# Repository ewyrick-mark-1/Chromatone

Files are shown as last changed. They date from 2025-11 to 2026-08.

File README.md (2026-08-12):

# Chromatone

**Author:** Elliot Wyrick

## Overview

Chromatone is an embedded audio visualizer running on the Raspberry Pi RP2350. It samples audio through the ADC, performs a real-time FFT, detects musical notes, and drives an RGB LED output based on the results.

## [Demo video:](https://youtu.be/pOVmz1aZbJg)

Watch the demo (https://youtu.be/pOVmz1aZbJg)

## Hardware

- **MCU:** Raspberry Pi RP2350 (overclocked to 300 MHz)
- **Input:** Analog microphone on ADC channel 0 (GPIO 40)
- **Output:** RGB LED via PWM on GPIO 37–39
- **Schematics/PCB:** KiCad project files located in `KiCad/`

## How It Works

Audio is captured at 20 kHz using DMA ping-pong buffers. Each buffer triggers a 16384 point FFT with 50% overlap and a Hanning window applied. Detected frequency peaks are mapped to MIDI notes (A0–C8), and the corresponding hue is output to the RGB LED.

Two display modes are available (toggled via `display_mode` in `main.c`):
- **Mode 0:** Logarithmic frequency spectrum
- **Mode 1:** Musical note detection

## Color Math

Each of the 12 chromatic notes is assigned a fixed hue evenly spaced around the color wheel (360° / 12 = 30° per note), with C at 0° (red) through B at 330° (pink).

Detected peaks are converted to a note index using the standard MIDI formula:

```
n = 12 × log₂(f / 440) + 69
```

When multiple notes are detected simultaneously, their hues are blended using a **circular weighted average**- each hue is converted to a unit vector on the color wheel, weighted by FFT magnitude, and the vectors are summed:

```
x = Σ( cos(hue_i) × weight_i )
y = Σ( sin(hue_i) × weight_i )
blended_hue = atan2(y, x)
```

This handles wraparound correctly (e.g. blending 10° and 350° yields 0°, not 180°).

The blended hue is then smoothed over time using an exponential moving average on the shortest angular path (15% per frame) to avoid jarring color jumps between notes.

Finally, the smoothed hue is converted from HSV (full saturation and brightness) to RGB via the standard piecewise HSV→RGB formula and output as an 8-bit PWM duty cycle on each channel.

## Build & Flash

This project uses [PlatformIO](https://platformio.org/) with the Proton board target.

```
pio run
pio run --target upload
```

Serial monitor at 115200 baud:
```
pio device monitor
```

Alternativly, and what I used during development, the platform IO extension works well. It provides gui upload and monitor buttons.

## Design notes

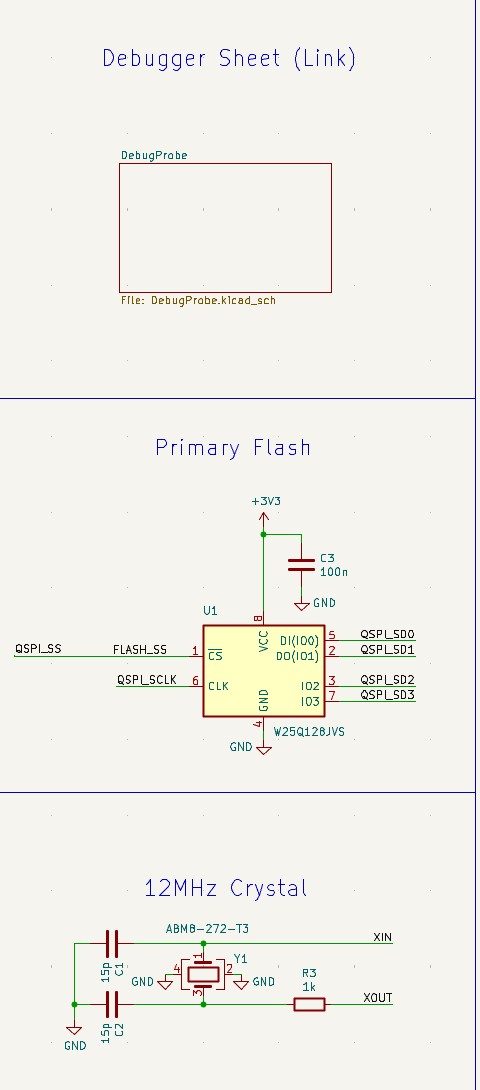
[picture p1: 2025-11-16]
KiCad/4% possibilities/Proton Schematics/Flash & XOSC schem.jpg

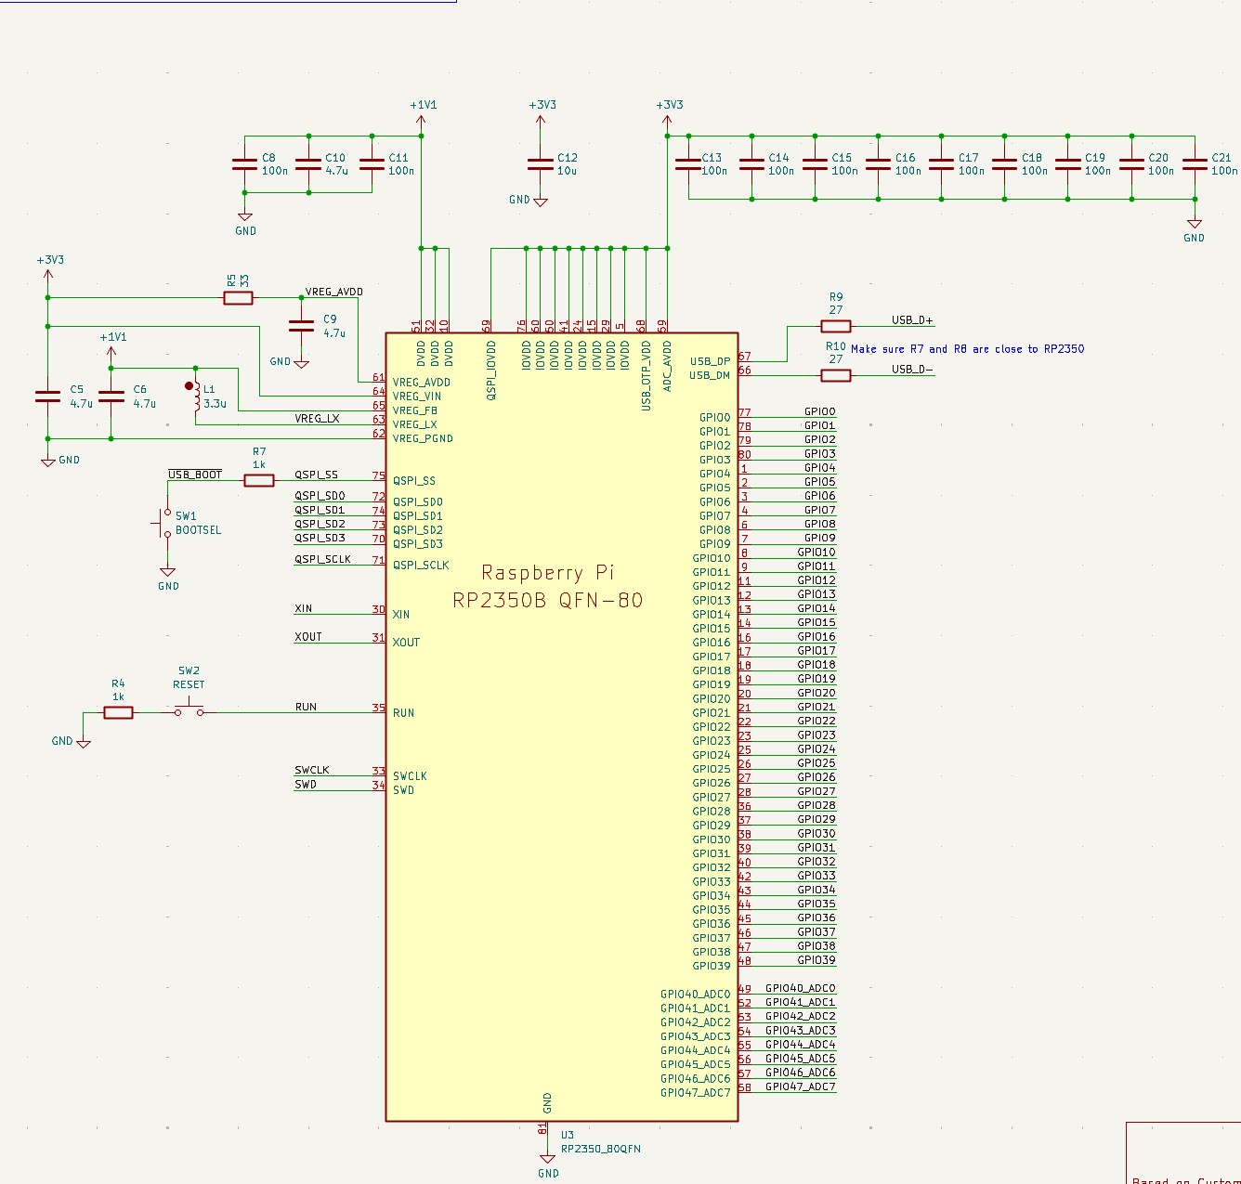
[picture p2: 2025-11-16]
KiCad/4% possibilities/Proton Schematics/Proton main schem.jpg

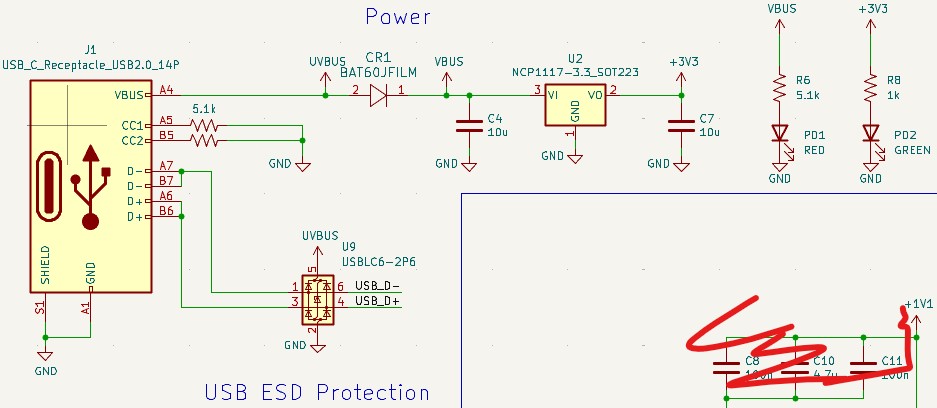
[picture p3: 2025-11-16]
KiCad/4% possibilities/Proton Schematics/Power schem.jpg

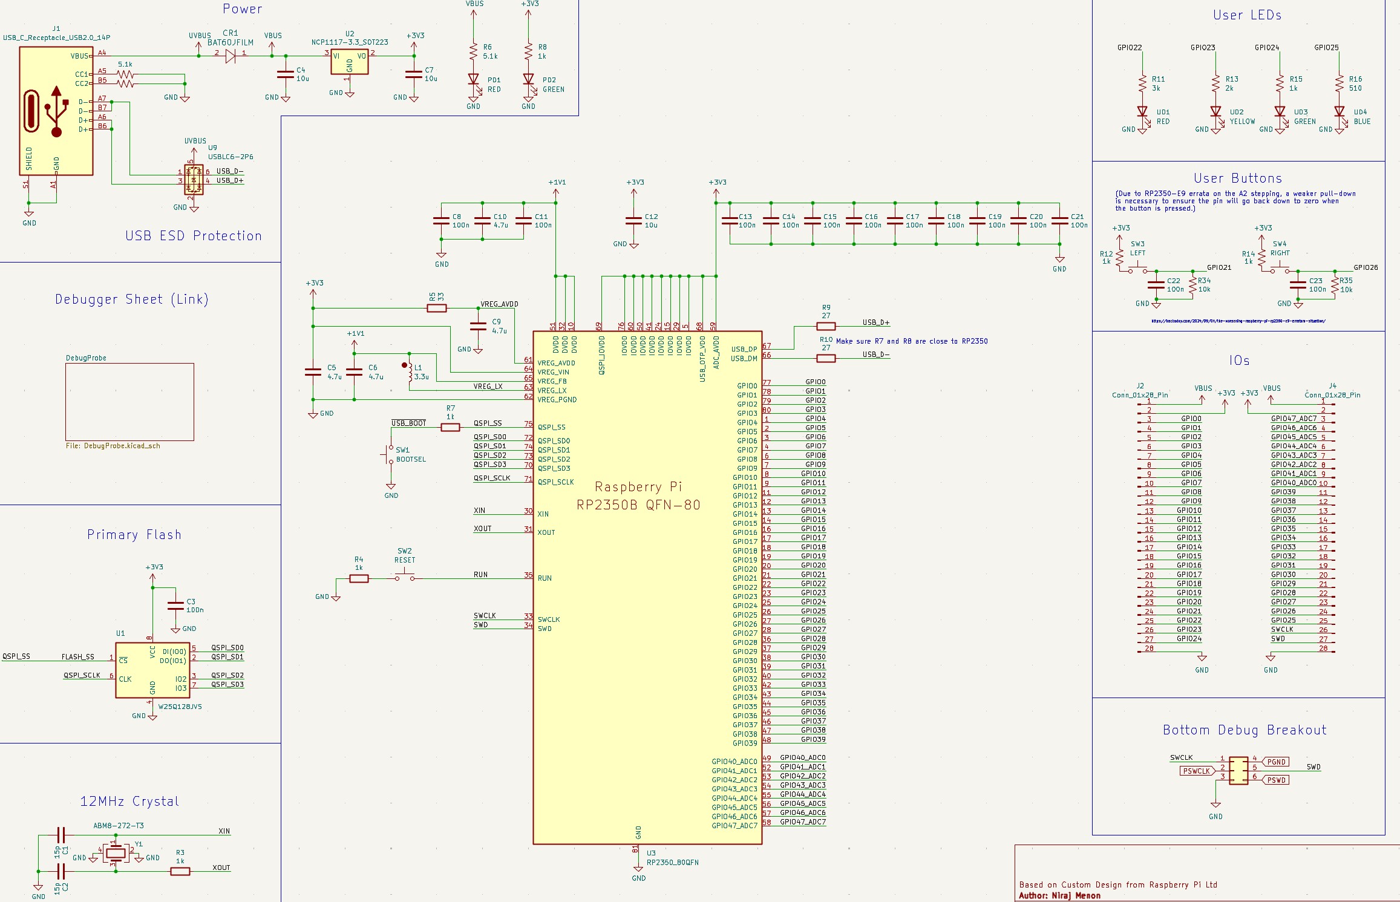
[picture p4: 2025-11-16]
KiCad/4% possibilities/Proton Schematics/Proton Schematic.jpg

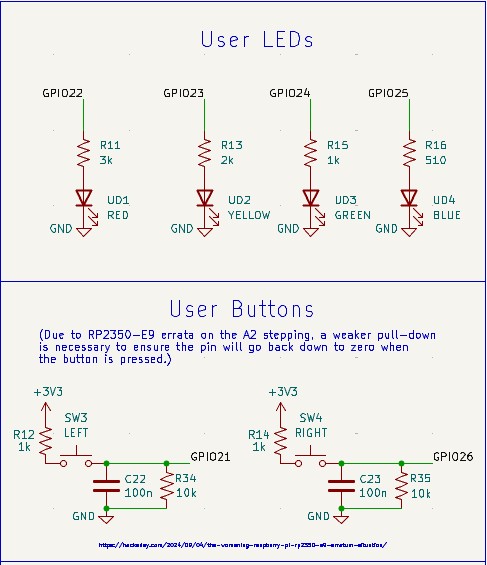
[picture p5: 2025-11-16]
KiCad/4% possibilities/Proton Schematics/optional Buttons schem.jpg

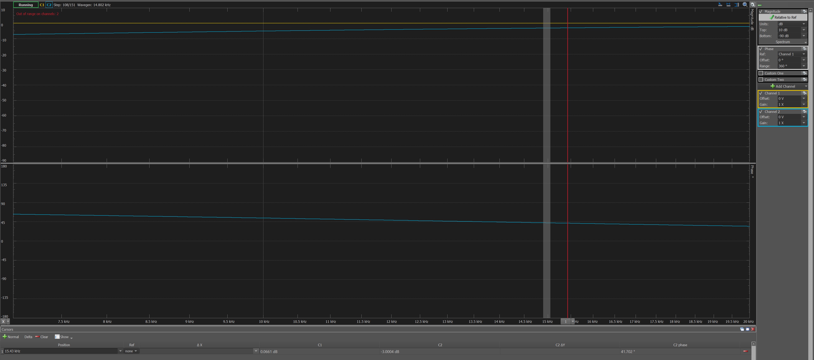
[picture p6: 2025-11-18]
HPF.jpg

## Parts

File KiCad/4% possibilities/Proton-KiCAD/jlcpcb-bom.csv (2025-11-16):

Designator | Footprint | Quantity | Value | LCSC Part #
C1, C2, C24, C25 | 402 | 4 | 15p | C1548
C10, C5, C6, C9 | 402 | 4 | 4.7u | C23733
C11, C13, C14, C15, C16, C17, C18, C19, C20, C21, C22, C23, C28, C29, C3, C30, C33, C35, C36, C37, C38, C39, C40, C41, C42, C8 | 402 | 26 | 100n | C1525
C12, C26, C4, C7 | 805 | 4 | 10u | C15850
C27, C32 | 603 | 2 | 10u | C19702
C31, C34 | 402 | 2 | 1u | C52923
CR1, CR2 | CR_60JFILM_STM | 2 | BAT60JFILM | C133103
D1 | 402 | 1 | RED | C397045
D2, D4 | 402 | 2 | GREEN | C434446
D3, D5 | 402 | 2 | YELLOW | C130721
J1, J5 | USB_C_Receptacle_G-Switch_GT-USB-7010ASV | 2 | USB_C_Receptacle_USB2.0_14P | C2988369
L1 | L_pol_2016 | 1 | 3.3u | C42411119
PD1, UD1 | 805 | 2 | RED | C2295
PD2, UD3 | 805 | 2 | GREEN | C2297
R1, R18, R19, R2, R6, R8 | 402 | 4 | 5.1k | C25905
R10, R21, R22, R9 | 402 | 4 | 27 | C137890
R11 | 402 | 1 | 3k | C25559
R13 | 402 | 1 | 2k | C4109
R16 | 402 | 1 | 510 | C25123
R12, R14, R15, R17, R20, R3, R4, R7 | 402 | 13 | 1k | C11702
R34, R35 | 402 | 2 | 10k | C25531
R23, R31, R33 | 402 | 5 | 470 | C25117
R30, R32 | 402 | 2 | 2k | C4109
R24, R25, R26, R27, R28, R29 | 402 | 6 | 100 | C25076
R5 | 402 | 1 | 33 | C25105
SW1 | SW_SPST_PTS647_Sx38 | 1 | BOOTSEL | C2689502
SW2 | SW_SPST_PTS647_Sx38 | 1 | RESET | C2689502
SW3 | SW_SPST_PTS647_Sx38 | 1 | LEFT | C2689502
SW4 | SW_SPST_PTS647_Sx38 | 1 | RIGHT | C2689502
U1 | SOIC-8_5.23x5.23mm_P1.27mm | 1 | W25Q128JVS | C97521
U10, U9 | SOT-666 | 2 | USBLC6-2P6 | C15999
U2 | SOT-223-3_TabPin2 | 1 | NCP1117-3.3_SOT223 | C26537
U3 | RP2350-QFN-80-1EP_10x10_P0.4mm_EP3.4x3.4mm_ThermalVias | 1 | RP2350_80QFN | C42415655
U4 | USON-8_UX_2x3x0p6_WIN | 1 | W25Q16JVUXIQ TR | C2843335
U5 | SOT-23-5 | 1 | AP2112K-3.3 | C23380830
U6 | RP2040-QFN-56 | 1 | RP2040 | C2040
U7, U8 | DCK5 | 2 | SN74AUP1T17DCKR | C2652100
UD2 | 805 | 1 | YELLOW | C2296
UD4 | 805 | 1 | BLUE | C2293
Y1, Y2 | Crystal_SMD_3225-4Pin_3.2x2.5mm | 2 | ABM8-272-T3 | C20625731

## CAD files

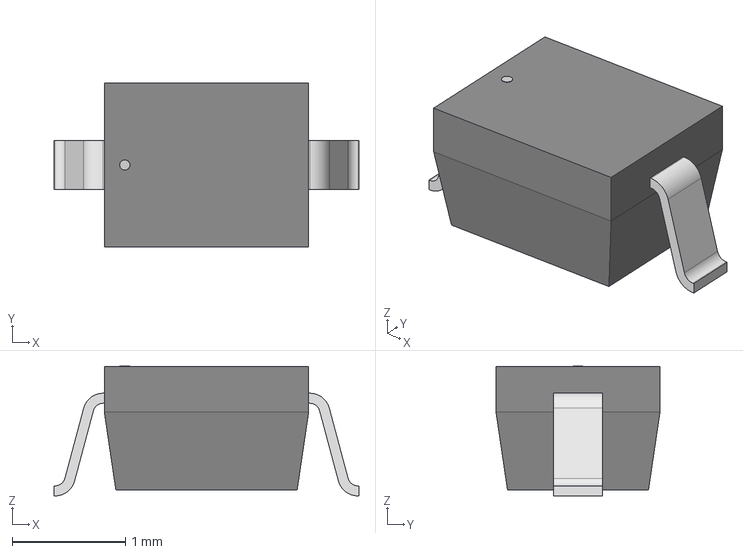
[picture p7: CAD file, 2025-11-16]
KiCad/4% possibilities/Proton-KiCAD/BAT60JFILM/CR_60JFILM_STM.step
2.69 x 1.45 x 1.15 mm

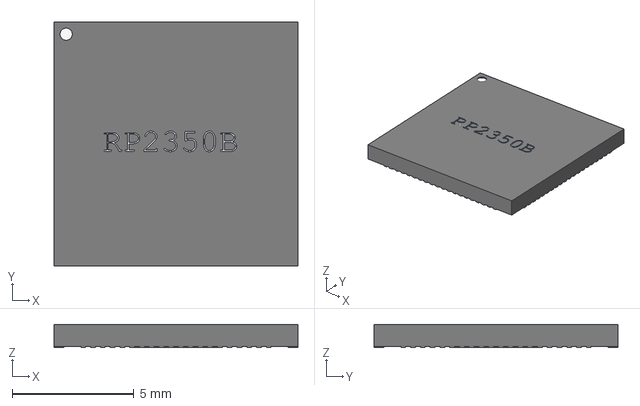
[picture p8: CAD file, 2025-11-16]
KiCad/4% possibilities/Proton-KiCAD/RP2350_QFN80.step
10.0 x 10.0 x 0.95 mm

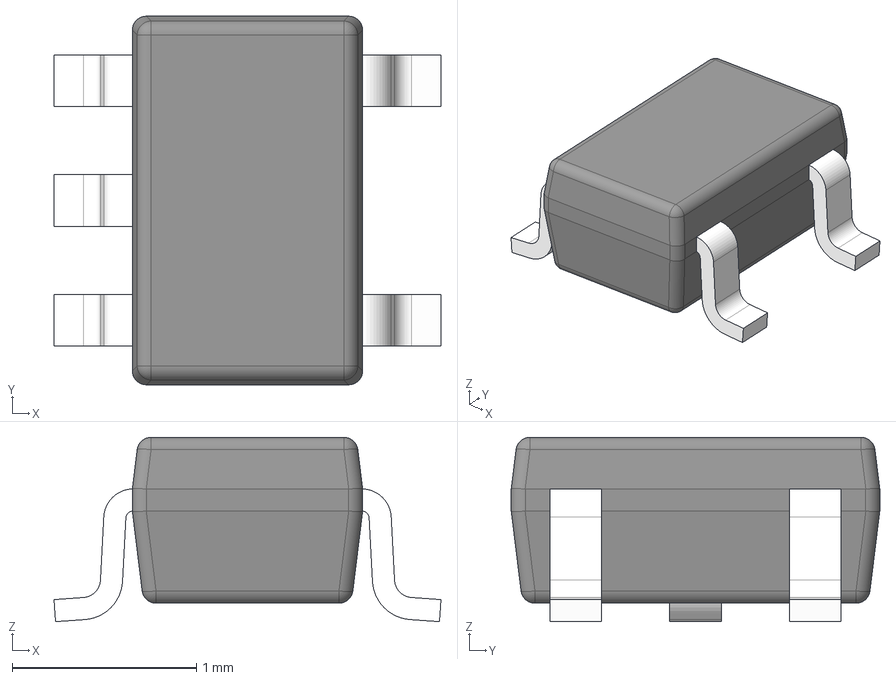
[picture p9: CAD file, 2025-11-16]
KiCad/4% possibilities/Proton-KiCAD/SN74AUP1T17DCKR/DCK0005A.stp
2.10 x 2.00 x 1.00 mm
BODY-SOT
LEAD-SOT x 5
PIN1-ID

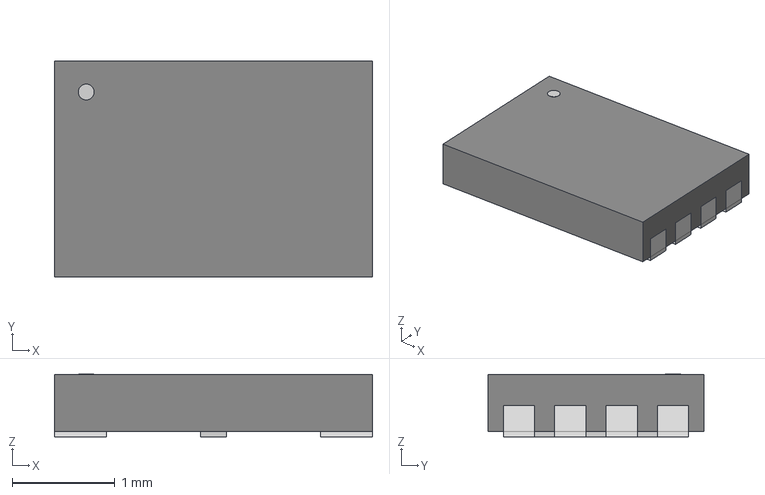
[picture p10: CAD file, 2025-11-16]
KiCad/4% possibilities/Proton-KiCAD/W25Q16JVUXIQ_TR/USON-8_UX_2x3x0p6_WIN.step
3.10 x 2.11 x 0.612 mm

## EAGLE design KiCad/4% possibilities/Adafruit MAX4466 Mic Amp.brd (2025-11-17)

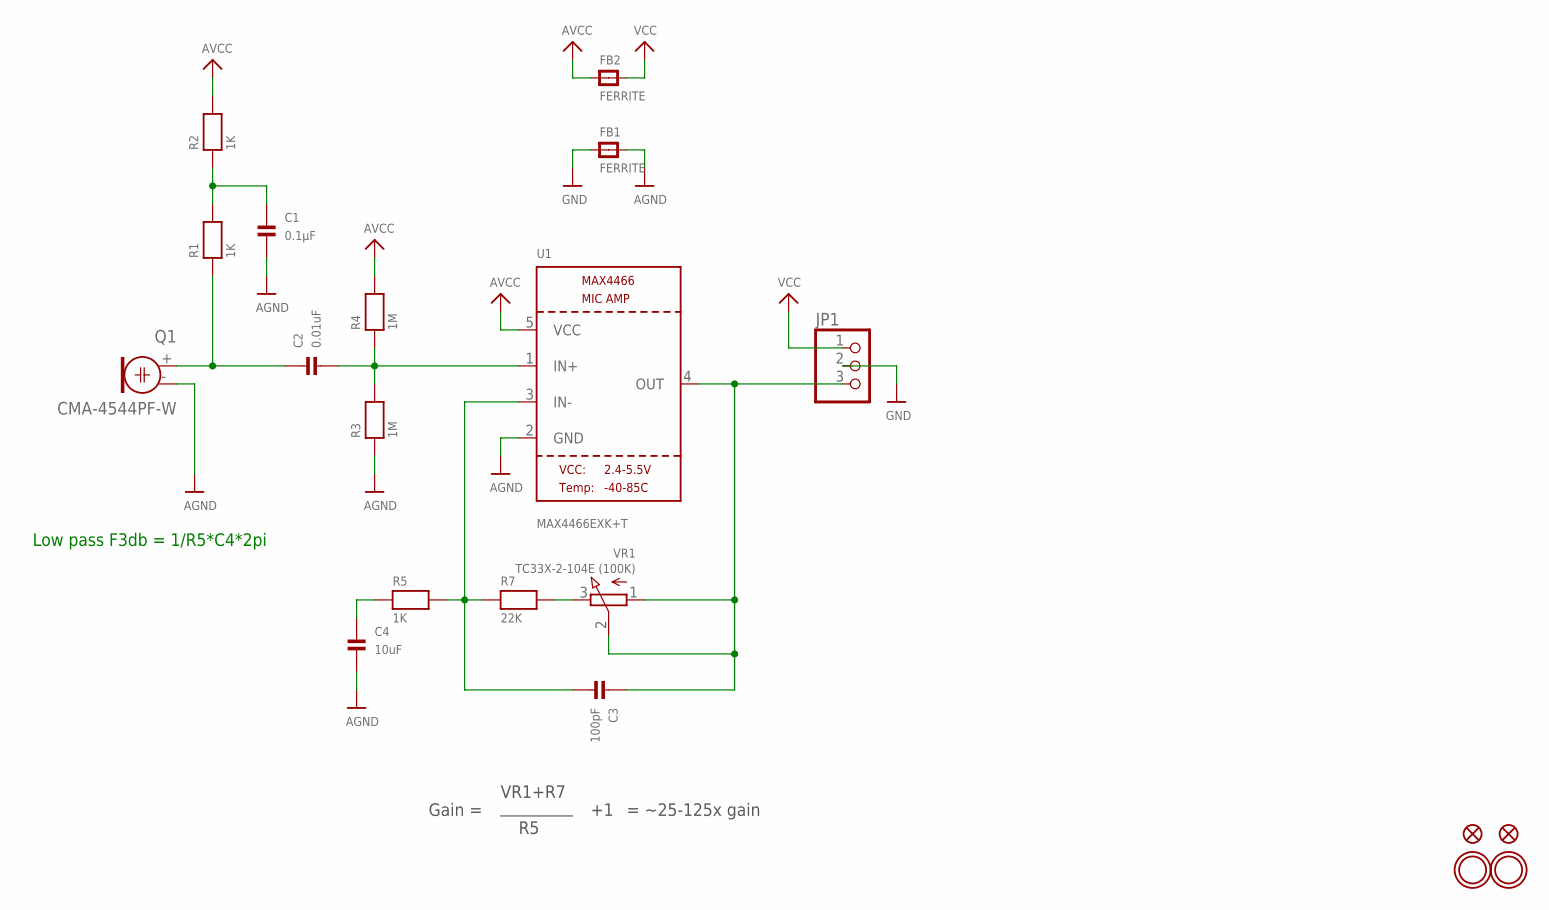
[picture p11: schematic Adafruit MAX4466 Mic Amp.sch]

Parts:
C1: 0.1µF; 0805
C2: 0.01uF; 0805
C3: 100pF; 0805
C4: 10uF; 0805
FB1, FB2: FERRITE; 0805
FID1, FID2: FIDUCIAL""; FIDUCIAL_1MM
JP1: HEADER-1X376MIL; 1X03_ROUND_76
Q1: CMA-4544PF-W; ELECTRET_9.7
R1, R2, R5: 1K; 0805
R3, R4: 1M; 0805
R7: 22K; 0805
U1: MAX4466EXK+T; SC70-5
U$11, U$14: MOUNTINGHOLE2.5; MOUNTINGHOLE_2.5_PLATED
VR1: TC33X-2-104E (100K); TRIMPOT_BOURNS_TC33X-2

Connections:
AGND: C1.2, C4.2, FB1.2, Q1.- (1), R3.1, U1.2 (GND)
AVCC: FB2.1, R2.2, R4.2, U1.5 (VCC)
GND: FB1.1, JP1.2
unnamed: C3.2, R5.2, R7.1, U1.3 (IN-)
unnamed: R7.2, VR1.3 (E)
unnamed: C2.1, Q1.+ (2), R1.1
unnamed: C1.1, R1.2, R2.1
unnamed: C2.2, R3.2, R4.1, U1.1 (IN+)
unnamed: C3.1, JP1.3, U1.4 (OUT), VR1.1 (A), VR1.2 (S)
unnamed: C4.1, R5.1
VCC: FB2.2, JP1.1

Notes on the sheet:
Gain =
VR1+R7
= ~25-125x gain
Low pass F3db = 1/R5*C4*2pi

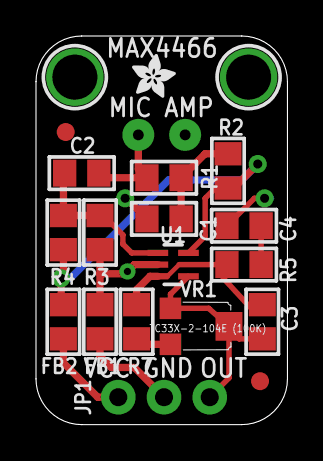
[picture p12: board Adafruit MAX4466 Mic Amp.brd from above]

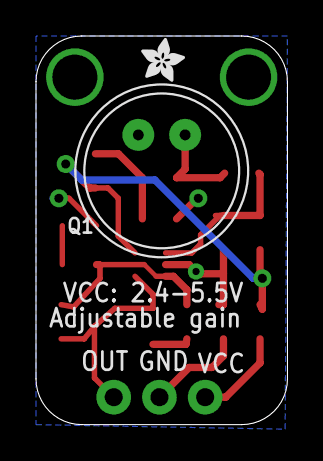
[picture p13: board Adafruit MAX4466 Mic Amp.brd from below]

Board: 2 copper layers, 14.0 x 21.6 mm, 22 parts (2 on the bottom side), 11 nets.

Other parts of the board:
U$16, U$17: ADAFRUIT_2.5MM

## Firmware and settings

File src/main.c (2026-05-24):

// Single-channel DMA-based FFT for instrument note detection
#include <stdio.h>
#include <string.h>
#include <math.h>
#include "hardware/adc.h"
#include "hardware/gpio.h"
#include "hardware/dma.h"
#include "hardware/irq.h"
#include "hardware/clocks.h"
#include "hardware/vreg.h"
#include "pico/stdlib.h"
#include "../include/color.h"
#include "../include/display.h"

// Define M_PI if not already defined
#ifndef M_PI
#define M_PI 3.14159265358979323846
#endif

// Configuration
#define FFT_SIZE 16384
#define NUM_BANDS 32
#define OVERLAP_PERCENT 50
#define STEP_SIZE (FFT_SIZE * (100 - OVERLAP_PERCENT) / 100)  // 50% overlap = 8192 step
#define NOISE_FLOOR_THRESHOLD 10.0f  // Ignore FFT magnitudes below this value

// Single-channel configuration for instrument range
#define SAMPLE_RATE 20000.0f
#define ADC_CHANNEL 0
#define GPIO_PIN 40
#define MIN_FREQ 27.0f   // A0 fundamental
#define MAX_FREQ 8000.0f // Upper instrument range

// DMA ping-pong buffers (fill STEP_SIZE at a time for 50% overlap)
static uint16_t adc_buffer[2][STEP_SIZE];
static volatile int filled_buffer_index = -1;
static volatile bool buffer_ready = false;

// Overlap buffer for 50% overlap
static uint16_t overlap_buffer[STEP_SIZE];

// DMA channels
static int dma_chan_0;
static int dma_chan_1;

// Debug counter
static volatile uint32_t fft_count = 0;

// Display mode toggle (0=spectrum, 1=notes) - change this to switch modes
static volatile bool display_mode = 1;

// FFT working buffers
static float fft_input[FFT_SIZE];
static float fft_real[FFT_SIZE];
static float fft_imag[FFT_SIZE];
static float magnitude[FFT_SIZE / 2];
static float spectrum[NUM_BANDS];

// Note: detected_note_t is now defined in display.h

// ----- forward declarations -----
void fft(float* real, float* imag, int n);
void apply_hanning_window(float* data, int n);
void calculate_magnitude(float* real, float* imag, float* mag, int n);
void map_to_bands(float* mag, float* bands, int fft_size, int num_bands,
                  float sample_rate, float min_freq, float max_freq);
void freq_to_note(float freq, char* note_str);
int find_peaks(detected_note_t* notes, int max_notes);
// visualize_spectrum and visualize_notes are now in display.h/display.c
void dma_handler(void);
void setup_adc_dma(void);
void process_fft_buffer(uint16_t* buffer);

// ------------------ FFT ------------------
void fft(float* real, float* imag, int n) {
    int j = 0;
    for (int i = 0; i < n - 1; i++) {
        if (i < j) {
            float tmp = real[i]; real[i] = real[j]; real[j] = tmp;
            tmp = imag[i]; imag[i] = imag[j]; imag[j] = tmp;
        }
        int k = n / 2;
        while (k <= j) { j -= k; k /= 2; }
        j += k;
    }

    for (int len = 2; len <= n; len *= 2) {
        float angle = -2.0f * M_PI / len;
        float wlen_real = cosf(angle);
        float wlen_imag = sinf(angle);

        for (int i = 0; i < n; i += len) {
            float w_real = 1.0f;
            float w_imag = 0.0f;
            for (int j = 0; j < len / 2; j++) {
                int idx1 = i + j;
                int idx2 = i + j + len / 2;
                float t_real = w_real * real[idx2] - w_imag * imag[idx2];
                float t_imag = w_real * imag[idx2] + w_imag * real[idx2];

                float u_real = real[idx1];
                float u_imag = imag[idx1];

                real[idx1] = u_real + t_real;
                imag[idx1] = u_imag + t_imag;
                real[idx2] = u_real - t_real;
                imag[idx2] = u_imag - t_imag;

                float w_temp = w_real;
                w_real = w_real * wlen_real - w_imag * wlen_imag;
                w_imag = w_temp * wlen_imag + w_imag * wlen_real;
            }
        }
    }
}

// ------------------ Window / mag / mapping / viz ------------------
void apply_hanning_window(float* data, int n) {
    for (int i = 0; i < n; i++) {
        float window = 0.5f * (1.0f - cosf(2.0f * M_PI * i / (n - 1)));
        data[i] *= window;
    }
}

void calculate_magnitude(float* real, float* imag, float* mag, int n) {
    for (int i = 0; i < n / 2; i++) {
        mag[i] = sqrtf(real[i] * real[i] + imag[i] * imag[i]);
    }
}

// Map FFT magnitude to logarithmic bands
void map_to_bands(float* mag, float* bands, int fft_size, int num_bands,
                  float sample_rate, float min_freq, float max_freq) {
    // Clear bands first
    for (int i = 0; i < num_bands; i++) {
        bands[i] = 0.0f;
    }

    float freq_per_bin = sample_rate / (float)fft_size;

    // Calculate bin range
    int bin_start = (int)(min_freq / freq_per_bin);
    int bin_end = (int)(max_freq / freq_per_bin);

    if (bin_end > fft_size / 2)
        bin_end = fft_size / 2;
    if (bin_start < 0)
        bin_start = 0;

    // Map to logarithmic frequency bands
    float log_min = logf(min_freq);
    float log_max = logf(max_freq);

    for (int bin = bin_start; bin < bin_end; bin++) {
        float bin_freq = bin * freq_per_bin;

        if (bin_freq < min_freq || bin_freq > max_freq)
            continue;

        float log_freq = logf(bin_freq);

        // Map to band index
        int band_idx = (int)((log_freq - log_min) / (log_max - log_min) * num_bands);

        if (band_idx >= 0 && band_idx < num_bands) {
            // Take maximum value in each band
            if (mag[bin] > bands[band_idx]) {
                bands[band_idx] = mag[bin];
            }
        }
    }
}


// Convert frequency to note name (A0-C8)
void freq_to_note(float freq, char* note_str) {
    if (freq < 20.0f) {
        strcpy(note_str, "---");
        return;
    }

    // Note names
    const char* notes[] = {"C", "C#", "D", "D#", "E", "F", "F#", "G", "G#", "A", "A#", "B"};

    // A4 = 440 Hz is note number 69 in MIDI (semitone 69 from C0)
    // Formula: n = 12 * log2(f / 440) + 69
    float semitone = 12.0f * log2f(freq / 440.0f) + 69.0f;
    int note_num = (int)(semitone + 0.5f); // Round to nearest semitone

    if (note_num < 0 || note_num > 127) {
        strcpy(note_str, "---");
        return;
    }

    int octave = (note_num / 12) - 1;
    int note_idx = note_num % 12;

    sprintf(note_str, "%s%d", notes[note_idx], octave);
}

// Find peaks in FFT magnitude array and convert to notes
int find_peaks(detected_note_t* notes, int max_notes) {
    int num_notes = 0;
    float threshold = 100.0f; // Minimum magnitude to consider as peak
    float freq_per_bin = SAMPLE_RATE / (float)FFT_SIZE;

    // Scan through FFT bins looking for local maxima
    for (int i = 10; i < FFT_SIZE / 2 - 10 && num_notes < max_notes; i++) {
        // Check if this is a local maximum
        if (magnitude[i] > threshold &&
            magnitude[i] > magnitude[i-1] &&
            magnitude[i] > magnitude[i+1] &&
            magnitude[i] > magnitude[i-2] &&
            magnitude[i] > magnitude[i+2]) {

            // Calculate frequency
            float freq = i * freq_per_bin;

            // Only include frequencies in instrument range
            if (freq >= MIN_FREQ && freq <= MAX_FREQ) {
                notes[num_notes].freq = freq;
                notes[num_notes].magnitude = magnitude[i];
                freq_to_note(freq, notes[num_notes].note);
                num_notes++;
            }
        }
    }

    return num_notes;
}

// visualize_notes and visualize_spectrum are now in display.c


// ------------------ DMA interrupt handler ------------------
void dma_handler(void) {
    // Check which DMA channel completed
    if (dma_hw->ints0 & (1u << dma_chan_0)) {
        dma_hw->ints0 = 1u << dma_chan_0;
        filled_buffer_index = 0;
        buffer_ready = true;
        gpio_put(24, 0);  // Toggle LED for debug

        // Reset channel 0 for next time it gets chained to
        dma_channel_set_write_addr(dma_chan_0, adc_buffer[0], false);
        dma_channel_set_trans_count(dma_chan_0, STEP_SIZE, false);
    }
    if (dma_hw->ints0 & (1u << dma_chan_1)) {
        dma_hw->ints0 = 1u << dma_chan_1;
        filled_buffer_index = 1;
        buffer_ready = true;
        gpio_put(24, 1);  // Toggle LED for debug

        // Reset channel 1 for next time it gets chained to
        dma_channel_set_write_addr(dma_chan_1, adc_buffer[1], false);
        dma_channel_set_trans_count(dma_chan_1, STEP_SIZE, false);
    }
}

// ------------------ ADC + DMA setup ------------------
void setup_adc_dma(void) {
    // Initialize ADC
    adc_init();
    adc_gpio_init(GPIO_PIN);
    adc_select_input(ADC_CHANNEL);

    // Configure ADC for free-running at 20 kHz
    // ADC clock = 48 MHz, divider = 48000000 / 20000 = 2400
    adc_set_clkdiv(2400.0f - 1.0f);

    // Setup FIFO for DMA
    adc_fifo_setup(
        true,    // Write to FIFO
        true,    // Enable DMA requests
        1,       // DREQ threshold
        false,   // No error bit
        false    // 12-bit samples (not 8-bit)
    );

    // Claim two DMA channels for ping-pong
    dma_chan_0 = dma_claim_unused_channel(true);
    dma_chan_1 = dma_claim_unused_channel(true);

    // Configure DMA channel 0
    dma_channel_config c0 = dma_channel_get_default_config(dma_chan_0);
    channel_config_set_transfer_data_size(&c0, DMA_SIZE_16);
    channel_config_set_read_increment(&c0, false);
    channel_config_set_write_increment(&c0, true);
    channel_config_set_dreq(&c0, DREQ_ADC);
    channel_config_set_chain_to(&c0, dma_chan_1);

    dma_channel_configure(
        dma_chan_0,
        &c0,
        adc_buffer[0],      // Write to buffer 0
        &adc_hw->fifo,      // Read from ADC FIFO
        STEP_SIZE,          // Transfer count (8192 for 50% overlap)
        false               // Don't start yet
    );

    // Configure DMA channel 1
    dma_channel_config c1 = dma_channel_get_default_config(dma_chan_1);
    channel_config_set_transfer_data_size(&c1, DMA_SIZE_16);
    channel_config_set_read_increment(&c1, false);
    channel_config_set_write_increment(&c1, true);
    channel_config_set_dreq(&c1, DREQ_ADC);
    channel_config_set_chain_to(&c1, dma_chan_0);

    dma_channel_configure(
        dma_chan_1,
        &c1,
        adc_buffer[1],      // Write to buffer 1
        &adc_hw->fifo,      // Read from ADC FIFO
        STEP_SIZE,          // Transfer count (8192 for 50% overlap)
        false               // Don't start yet
    );

    // Enable DMA interrupts
    dma_channel_set_irq0_enabled(dma_chan_0, true);
    dma_channel_set_irq0_enabled(dma_chan_1, true);

    irq_set_exclusive_handler(DMA_IRQ_0, dma_handler);
    irq_set_enabled(DMA_IRQ_0, true);

    // Start ADC and first DMA channel
    adc_run(true);
    dma_channel_start(dma_chan_0);
}

// Process FFT with 50% overlap
void process_fft_buffer(uint16_t* new_buffer) {
    fft_count++;

    // Combine overlap buffer (first 8192) with new data (next 8192)
    // First copy overlap buffer to fft_input
    for (int i = 0; i < STEP_SIZE; i++) {
        fft_input[i] = (float)overlap_buffer[i];
    }

    // Then copy all of new buffer (which is STEP_SIZE samples)
    for (int i = 0; i < STEP_SIZE; i++) {
        fft_input[STEP_SIZE + i] = (float)new_buffer[i];
    }

    // Save new buffer for next overlap
    memcpy(overlap_buffer, new_buffer, STEP_SIZE * sizeof(uint16_t));

    // Compute DC offset
    float dc = 0.0f;
    for (int i = 0; i < FFT_SIZE; i++) {
        dc += fft_input[i];
    }
    dc /= (float)FFT_SIZE;

    // Normalize to ±1.0 range (12-bit ADC)
    for (int i = 0; i < FFT_SIZE; i++) {
        fft_input[i] = (fft_input[i] - dc) / 2048.0f;
    }

    // Apply Hanning window
    apply_hanning_window(fft_input, FFT_SIZE);

    // Prepare for FFT
    for (int i = 0; i < FFT_SIZE; i++) {
        fft_real[i] = fft_input[i];
        fft_imag[i] = 0.0f;
    }

    // Perform FFT
    fft(fft_real, fft_imag, FFT_SIZE);
    calculate_magnitude(fft_real, fft_imag, magnitude, FFT_SIZE);

    // Apply noise floor threshold
    for (int i = 0; i < FFT_SIZE / 2; i++) {
        if (magnitude[i] < NOISE_FLOOR_THRESHOLD) {
            magnitude[i] = 0.0f;
        }
    }

    // Map to logarithmic bands
    map_to_bands(magnitude, spectrum, FFT_SIZE, NUM_BANDS,
                 SAMPLE_RATE, MIN_FREQ, MAX_FREQ);

    // Print debug info every 10 FFTs (only in spectrum mode)
    if (fft_count % 10 == 0 && display_mode == 0) {
        printf("[FFT #%lu] ", fft_count);
    }

    // Visualize based on display mode
    if (display_mode == 0) {
        // Mode 0: Show spectrum
        visualize_spectrum(spectrum, NUM_BANDS);
    } else {
        // Mode 1: Show detected notes
        detected_note_t notes[20]; // Max 20 notes
        int num_notes = find_peaks(notes, 20);
        visualize_notes(notes, num_notes);
    }
}

// ------------------ Main ------------------
int main() {
    // Increase voltage for stable overclocking
    //vreg_set_voltage(VREG_VOLTAGE_1_20);
    //sleep_ms(10);

    // Overclock to 300 MHz for faster FFT processing
    set_sys_clock_khz(300000, true);

    stdio_init_all();
    sleep_ms(1000);

    // LED heartbeat
    gpio_init(24);
    gpio_set_dir(24, GPIO_OUT);
    gpio_put(24, 1);

    // Initialize RGB PWM output on pins 37-39
    setup_rgb_pwm();

    uint32_t actual_freq_khz = clock_get_hz(clk_sys) / 1000;

    printf("\n=== Single-Channel DMA FFT: Instrument Note Detection ===\n");
    printf("CPU Clock: %lu MHz (requested 300 MHz)\n", actual_freq_khz / 1000);
    printf("Change display_mode variable (line 46) to toggle: 0=Spectrum, 1=Note Detection\n");
    printf("Range: %.1f Hz - %.1f kHz (A0 to upper instrument range)\n",
           MIN_FREQ, MAX_FREQ / 1000.0f);
    printf("Sample rate: %.1f kHz, FFT Size: %d\n",
           SAMPLE_RATE / 1000.0f, FFT_SIZE);
    printf("Frequency resolution: %.2f Hz\n", SAMPLE_RATE / FFT_SIZE);
    printf("Overlap: %d%%, Update rate: ~%.1f Hz\n\n",
           OVERLAP_PERCENT, SAMPLE_RATE / STEP_SIZE);

    // Initialize overlap buffer with zeros
    memset(overlap_buffer, 0, STEP_SIZE * sizeof(uint16_t));

    // Initialize spectrum
    for (int i = 0; i < NUM_BANDS; i++) {
        spectrum[i] = 0.0f;
    }

    // Setup ADC and DMA
    setup_adc_dma();

    printf("Waiting for initial buffer fill...\n");
    sleep_ms(1000);

    printf("Starting FFT processing...\n\n");

    // Main loop: wait for DMA buffers and process
    while (1) {
        // Process FFT if buffer ready
        if (buffer_ready) {
            buffer_ready = false;

            // Process the filled buffer
            process_fft_buffer(adc_buffer[filled_buffer_index]);
        }

        tight_loop_contents();
    }

    return 0;
}

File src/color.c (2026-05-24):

#include "../include/color.h"
#include <math.h>
#include "hardware/pwm.h"
#include "hardware/gpio.h"

// Note hue mapping: 12 chromatic notes mapped to color wheel
// Each note is 30 degrees apart (360/12 = 30)
static const float NOTE_HUES[12] = {
    0.0f,    // C  - Red
    30.0f,   // C# - Orange
    60.0f,   // D  - Yellow
    90.0f,   // D# - Yellow-Green
    120.0f,  // E  - Green
    150.0f,  // F  - Cyan-Green
    180.0f,  // F# - Cyan
    210.0f,  // G  - Sky Blue
    240.0f,  // G# - Blue
    270.0f,  // A  - Purple
    300.0f,  // A# - Magenta
    330.0f   // B  - Pink
};

void setup_rgb_pwm(void) {
    // Initialize GPIO pins for PWM function
    gpio_set_function(PWM_R_PIN, GPIO_FUNC_PWM);
    gpio_set_function(PWM_G_PIN, GPIO_FUNC_PWM);
    gpio_set_function(PWM_B_PIN, GPIO_FUNC_PWM);

    // Get PWM slice numbers for each pin
    // GPIO 37 -> Slice 2, Channel B (37/2 = 18, 18%8 = 2)
    // GPIO 38 -> Slice 3, Channel A (38/2 = 19, 19%8 = 3)
    // GPIO 39 -> Slice 3, Channel B (39/2 = 19, 19%8 = 3)
    uint slice_r = pwm_gpio_to_slice_num(PWM_R_PIN);
    uint slice_g = pwm_gpio_to_slice_num(PWM_G_PIN);
    uint slice_b = pwm_gpio_to_slice_num(PWM_B_PIN);

    // Set clock divider to match lab-5-pwm configuration
    pwm_set_clkdiv(slice_r, 150.0f);
    pwm_set_clkdiv(slice_g, 150.0f);
    pwm_set_clkdiv(slice_b, 150.0f);

    // Configure PWM for 8-bit resolution
    pwm_set_wrap(slice_r, PWM_WRAP);
    pwm_set_wrap(slice_g, PWM_WRAP);
    pwm_set_wrap(slice_b, PWM_WRAP);

    // Set initial duty cycle to OFF (LOW gate = NMOS off = LED off)
    pwm_set_gpio_level(PWM_R_PIN, 0);
    pwm_set_gpio_level(PWM_G_PIN, 0);
    pwm_set_gpio_level(PWM_B_PIN, 0);

    // Enable PWM slices
    pwm_set_enabled(slice_r, true);
    pwm_set_enabled(slice_g, true);
    pwm_set_enabled(slice_b, true);
}

void set_rgb_pwm(uint8_t r, uint8_t g, uint8_t b) {
    // Common anode + NMOS: Inverted logic
    // Higher RGB values = lower duty cycle to cathode = brighter LED
    pwm_set_gpio_level(PWM_R_PIN, r);
    pwm_set_gpio_level(PWM_G_PIN,  g);
    pwm_set_gpio_level(PWM_B_PIN,  b);
}

void hsv_to_rgb(float h, float s, float v, uint8_t* r, uint8_t* g, uint8_t* b) {
    // Normalize hue to 0-360
    while (h >= 360.0f) h -= 360.0f;
    while (h < 0.0f) h += 360.0f;

    // Clamp saturation and value
    if (s > 1.0f) s = 1.0f;
    if (s < 0.0f) s = 0.0f;
    if (v > 1.0f) v = 1.0f;
    if (v < 0.0f) v = 0.0f;

    float c = v * s;  // Chroma
    float x = c * (1.0f - fabsf(fmodf(h / 60.0f, 2.0f) - 1.0f));
    float m = v - c;

    float r_prime, g_prime, b_prime;

    if (h < 60.0f) {
        r_prime = c; g_prime = x; b_prime = 0;
    } else if (h < 120.0f) {
        r_prime = x; g_prime = c; b_prime = 0;
    } else if (h < 180.0f) {
        r_prime = 0; g_prime = c; b_prime = x;
    } else if (h < 240.0f) {
        r_prime = 0; g_prime = x; b_prime = c;
    } else if (h < 300.0f) {
        r_prime = x; g_prime = 0; b_prime = c;
    } else {
        r_prime = c; g_prime = 0; b_prime = x;
    }

    *r = (uint8_t)((r_prime + m) * 255.0f);
    *g = (uint8_t)((g_prime + m) * 255.0f);
    *b = (uint8_t)((b_prime + m) * 255.0f);
}

int get_note_index(float freq) {
    if (freq < 20.0f) {
        return -1;  // Invalid frequency
    }

    // MIDI formula: n = 12 * log2(f / 440) + 69
    float semitone = 12.0f * log2f(freq / 440.0f) + 69.0f;
    int note_num = (int)(semitone + 0.5f);  // Round to nearest

    if (note_num < 0 || note_num > 127) {
        return -1;
    }

    // Return note index 0-11 (C=0, C#=1, ... B=11)
    return note_num % 12;
}

float get_note_hue(int note_idx) {
    if (note_idx < 0 || note_idx > 11) {
        return 0.0f;  // Default to red for invalid index
    }
    return NOTE_HUES[note_idx];
}

void note_index_to_rgb(int note_idx, float magnitude, uint8_t* r, uint8_t* g, uint8_t* b) {
    if (note_idx < 0 || note_idx > 11) {
        // Invalid note - turn off LED
        *r = 0;
        *g = 0;
        *b = 0;
        return;
    }

    // Get hue for this note
    float hue = NOTE_HUES[note_idx];

    // Full saturation, brightness based on magnitude
    float saturation = 1.0f;
    float value = magnitude;

    // Clamp value to 0-1 range
    if (value > 1.0f) value = 1.0f;
    if (value < 0.0f) value = 0.0f;

    // Ensure minimum brightness when note is detected
    if (value < 0.2f) value = 0.2f;

    hsv_to_rgb(hue, saturation, value, r, g, b);
}

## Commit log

2025-11-17 PCB V1
    [Adafruit MAX4466 Mic Amp.brd, Adafruit MAX4466 Mic Amp.sch, ece362proj.kicad_sch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]
2025-11-18 Filters done
    Bandpass is so zesty bro
    [Filters.kicad_pcb, Filters.kicad_sch]
2025-11-18 Expand FFT range from 2kHz-20kHz to 20Hz-20kHz using 3 ADC channels
    Implemented a 3-channel ADC/DMA system with different sample rates optimized
    for each frequency range based on Nyquist theorem:
    - Channel 0 (GPIO26): 20-7447 Hz @ 16 kHz sample rate (15.625 Hz resolution)
    - Channel 1 (GPIO27): 7242-14773 Hz @ 32 kHz sample rate (31.25 Hz resolution)
    - Channel 2 (GPIO28): 14573-22000 Hz @ 48 kHz sample rate (46.875 Hz resolution)
    Key improvements:
    - Sequential time-division multiplexing for independent sample rates
    - Staggered DMA start (10ms offsets) to prevent simultaneous FFT processing
    - Priority-based processing (low freq > mid freq > high freq)
    - Logarithmic frequency mapping for full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
    [main.c]
2025-11-18 LTspice confirm
    [Filters.kicad_sch]
2025-11-19 Updated filters
2025-11-21 Revert "27 - 8kHz single FFT with note detection and overclock"
    This reverts commit 01ecf81b79f251795c46a9fa0a58924b9dde3f12.
    [main.c]
2025-11-23 pwm led output working
2025-11-23 smooting + weighted hue averaging
    looks much more pretty and a little smoother. ~2 hz
2026-05-24 Fix PWM pin mapping and LED logic
    Correct PWM pin assignments to match physical wiring and update LED drive logic for NMOS gating: swap R/G/B pin defines, initialize PWM outputs LOW (LEDs off), and use non-inverted duty values in set_rgb_pwm. Include hardware/pwm.h and define M_PI in display.c; use pwm_set_gpio_level to explicitly turn LEDs off when no notes detected. Raise audio detection thresholds (NOISE_FLOOR_THRESHOLD and peak threshold) to reduce noise/false positives in FFT peak detection.
    [color.c, color.h, display.c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]
2026-08-12 Update README
    pico->rp2350 smh

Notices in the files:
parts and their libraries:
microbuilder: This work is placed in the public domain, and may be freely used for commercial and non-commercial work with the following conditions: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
